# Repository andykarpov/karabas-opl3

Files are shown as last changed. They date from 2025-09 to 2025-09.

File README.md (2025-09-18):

## Karabas-OPL3

Simple OPL3 sound card for ZX Spectrum (NemoBus). 
Inspired by a BomgeMoon soundcard :)

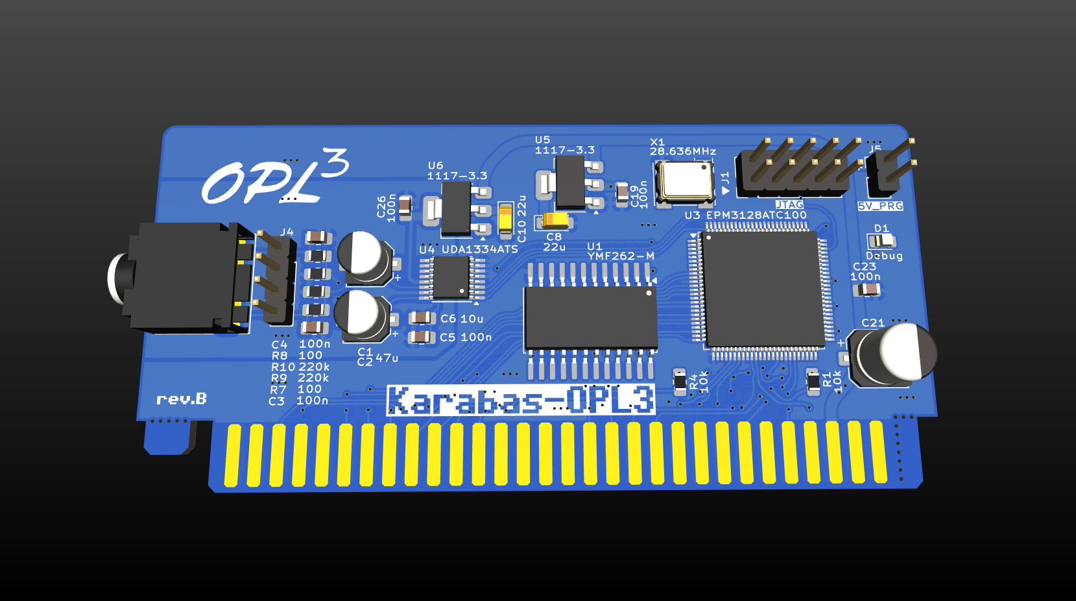
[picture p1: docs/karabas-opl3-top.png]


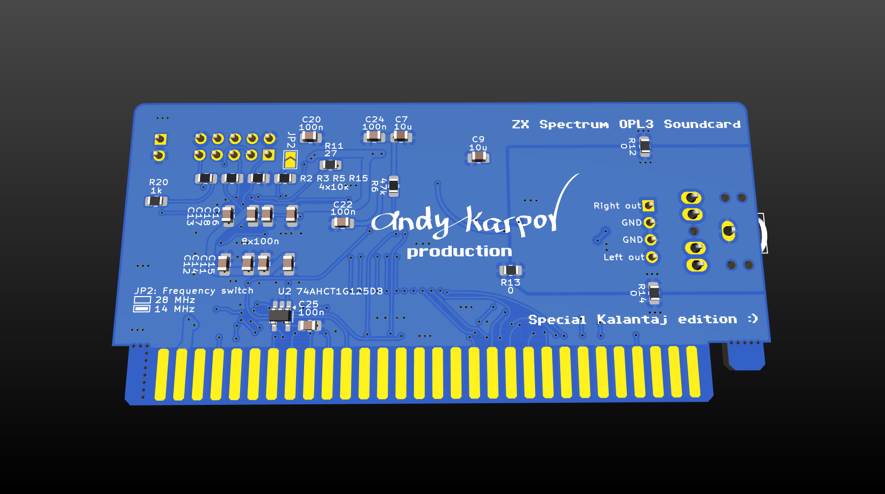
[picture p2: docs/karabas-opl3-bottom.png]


### Tech specs

* OPL3 sound by YMF-262-M
* 16-bit DAC UDA1334A
* EPM3128 CPLD
* Low profile PCB: 92x44mm (standard) and 131x44mm (xxl version)
* 5V only power required

### Changelog & current status

* Rev.A - initial release
* Rev.B - reduced pcb size, removed config switch

### Related projects

* BomgeMoon - [link](https://github.com/Kulicheg/BomgeMoon)
* ZX-Multisound - [link](https://github.com/UzixLS/zx-multisound)
* Turbo Sound FM - [link](http://www.nedopc.com/TURBOSOUND/ts-fm.php)
* ZXM-SoundCard - [link](http://micklab.ru/My%20Soundcard/ZXMSoundCard.htm)
* ZXM-GeneralSound - [link](http://micklab.ru/My%20Soundcard/ZXMGeneralSound.htm)
* NeoGS - [link](http://www.nedopc.com/gs/ngs.php)

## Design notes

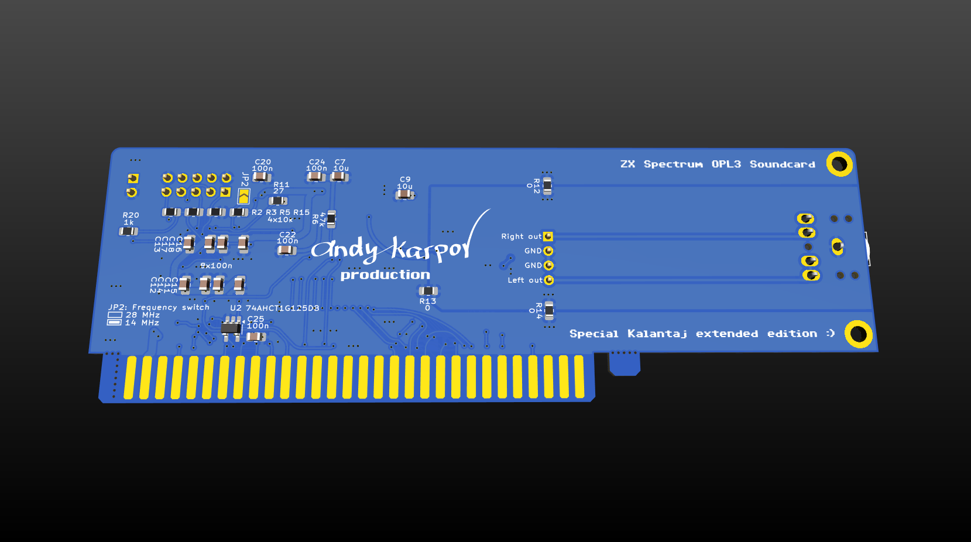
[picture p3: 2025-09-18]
docs/karabas-opl3-xxl-bottom.png

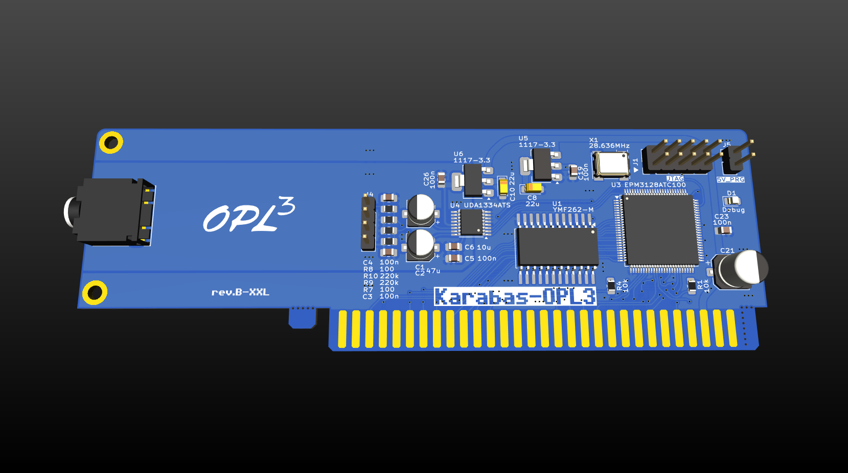
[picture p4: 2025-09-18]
docs/karabas-opl3-xxl-top.png

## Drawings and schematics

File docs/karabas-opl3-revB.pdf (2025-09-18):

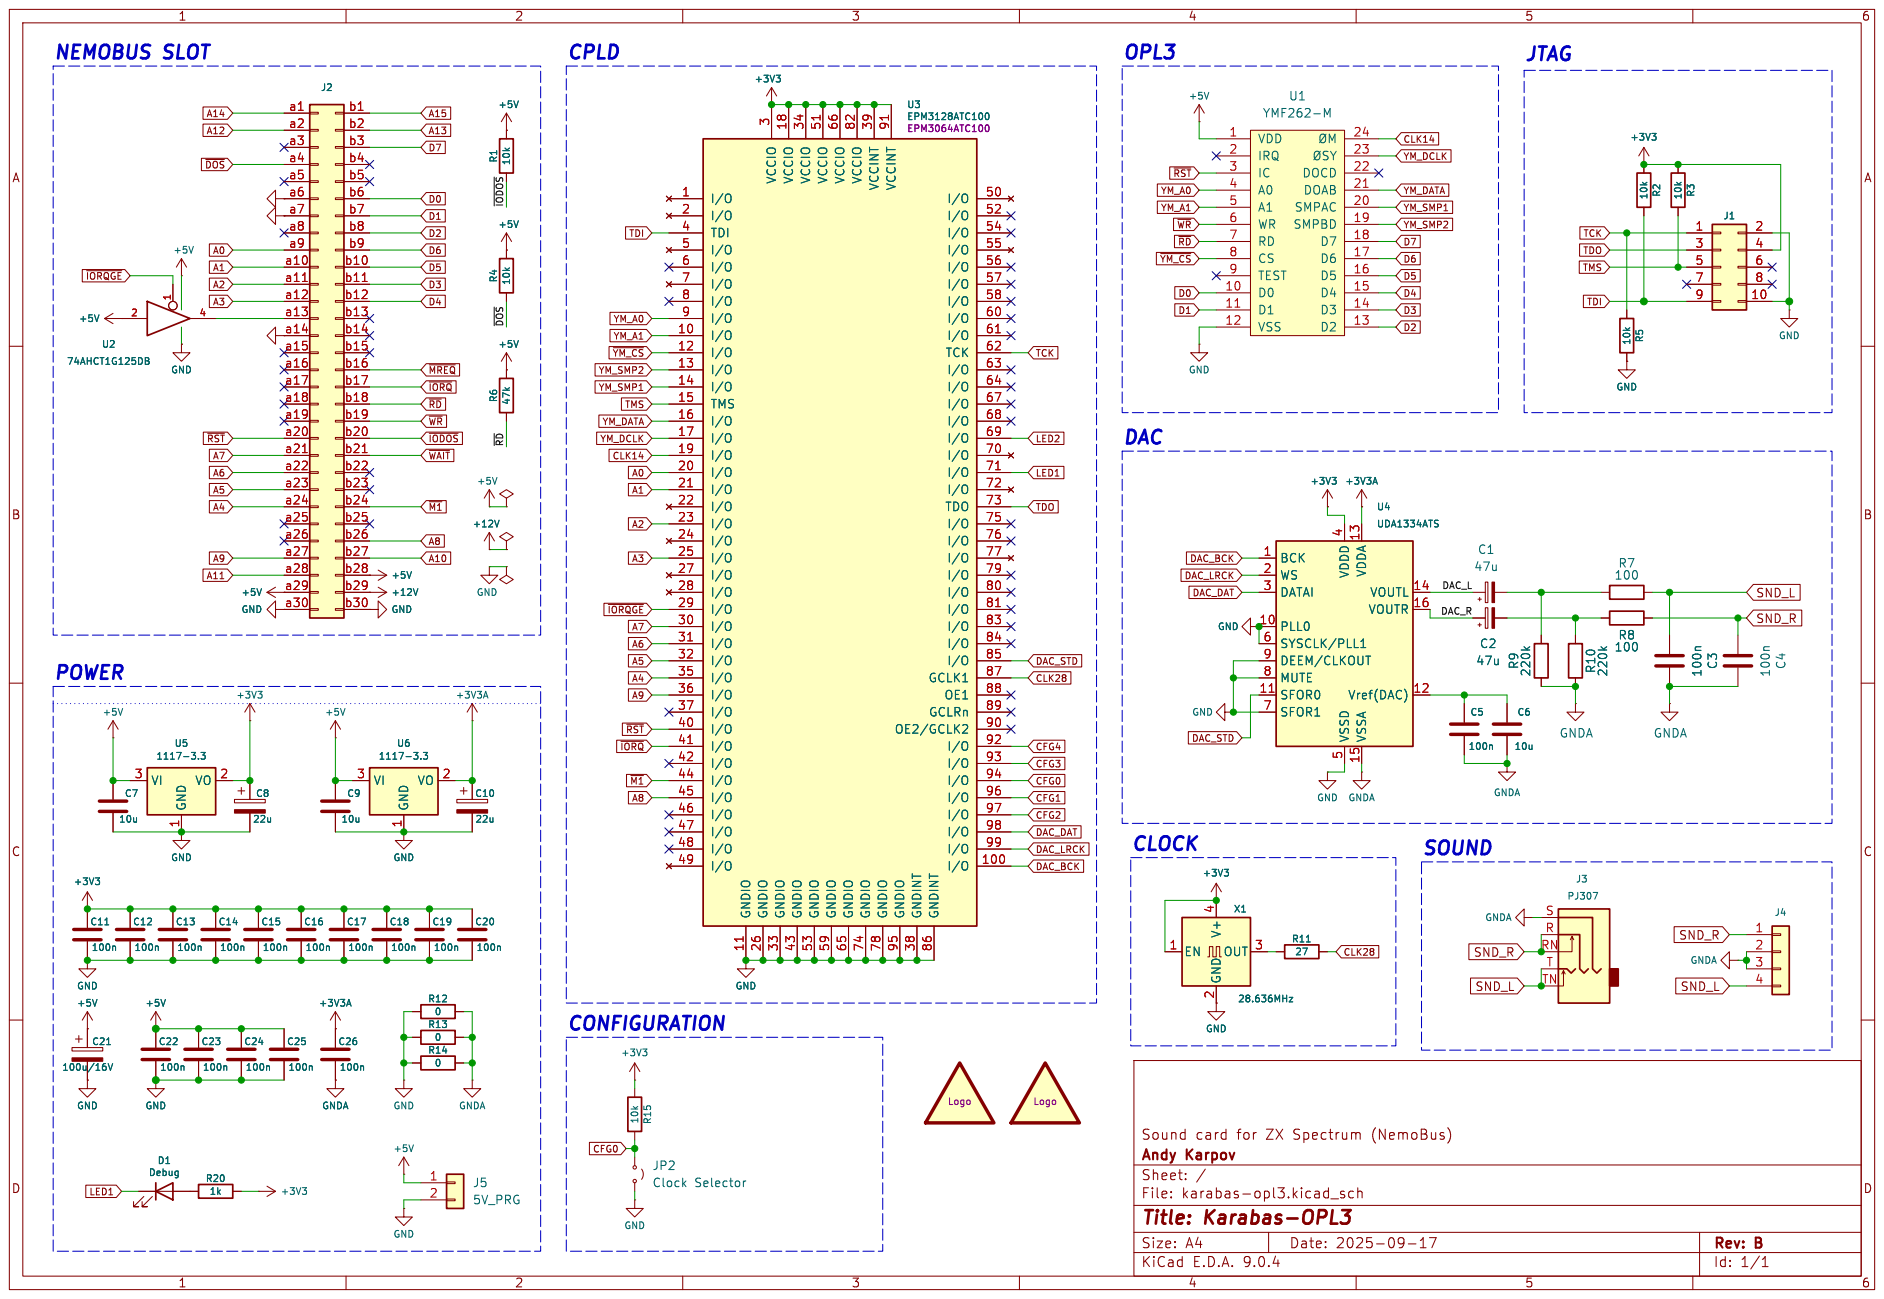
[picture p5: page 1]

3 GNDIO 33 VCCIO 18 GNDIO 43 VCCIO 34 GNDIO 53 VCCIO 51 GNDIO 59 VCCIO 66 GNDIO 65 VCCIO 82 GNDIO 74 VCCINT 39 GNDIO 78 VCCINT 91 GNDIO 95 GNDINT 38 GNDINT 86

5 VDDA 13 VSSA 15 VOUTL 14 VOUTR 16 Vref(DAC) 12 10k R5

5 VDDA 13 VSSA 15 VOUTL 14 VOUTR 16 Vref(DAC) 12 U4 UDA1334ATS GND

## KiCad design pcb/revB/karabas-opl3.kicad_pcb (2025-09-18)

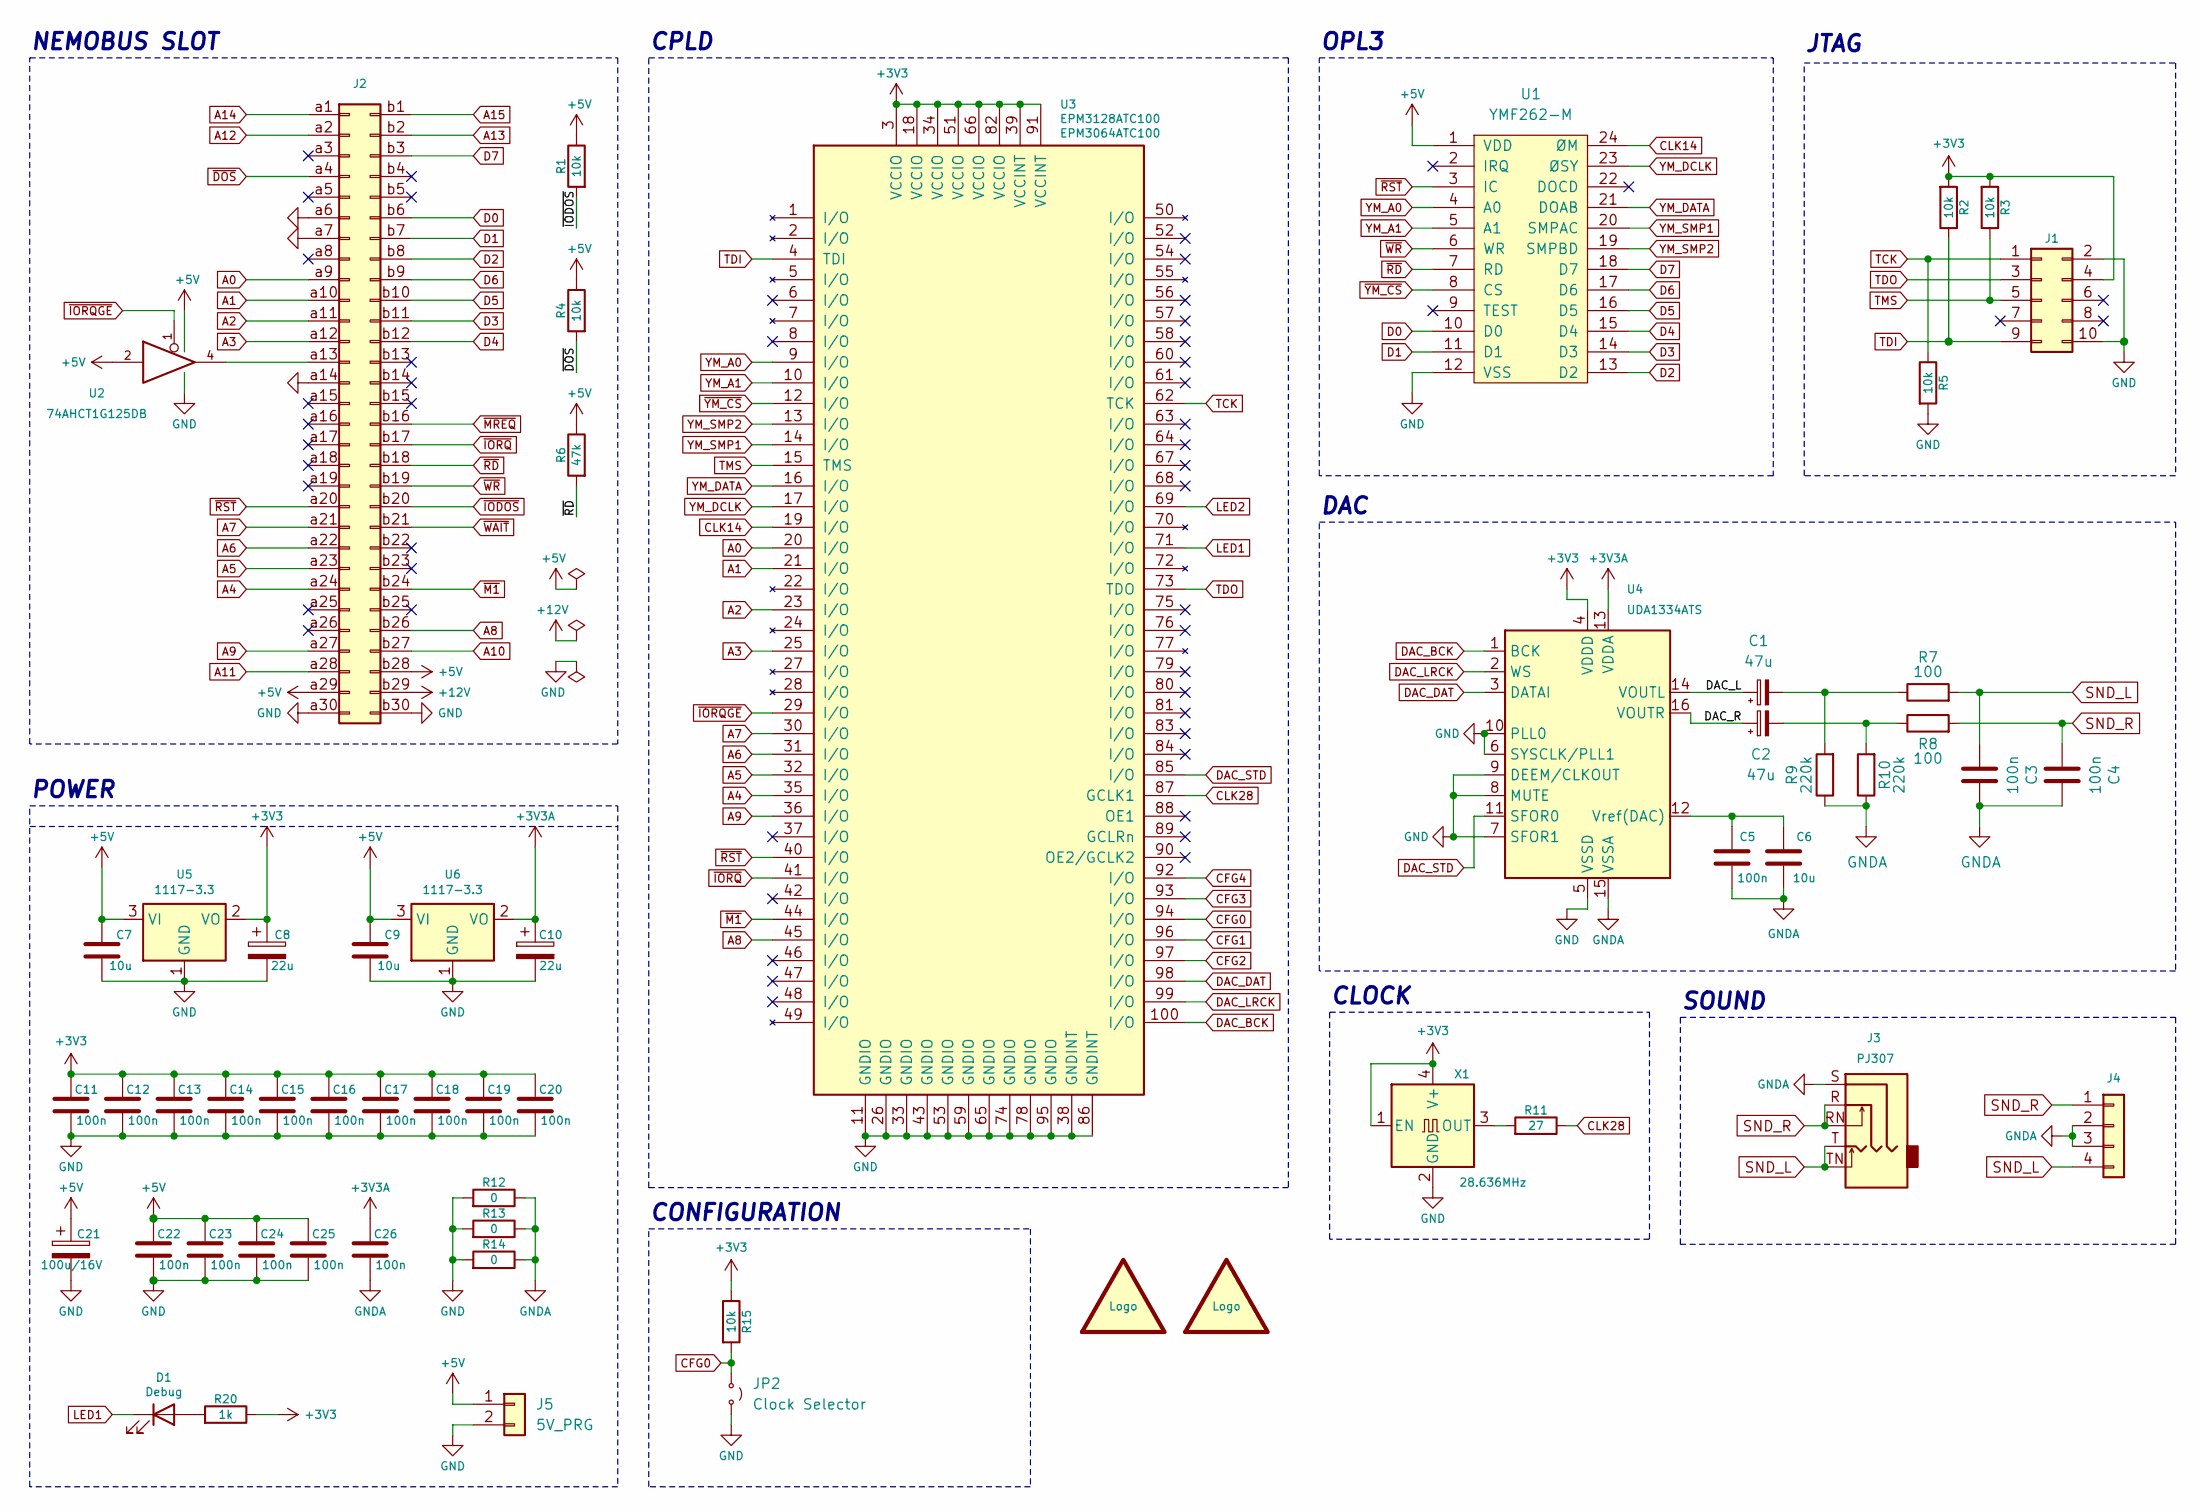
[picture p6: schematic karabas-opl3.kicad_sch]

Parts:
C1, C2: 47u; CP_Elec_5x5.9
C3, C4, C5, C11, C12, C13, C14, C15, C16, C17, C18, C19, C20, C22, C23, C24, C25, C26: 100n; C_0805_2012Metric_Pad1.18x1.45mm_HandSolder
C6, C7, C9: 10u; C_0805_2012Metric_Pad1.18x1.45mm_HandSolder
C8, C10: 22u; CP_EIA-3216-18_Kemet-A_HandSolder
C21: 100u/16V; CP_Elec_6.3x7.7
D1: Debug; LED_0805_2012Metric_Pad1.15x1.40mm_HandSolder
J1: Conn_02x05_Odd_Even; PinHeader_2x05_P2.54mm_Vertical
J2: Conn_02x30_Row_Letter_First; ZX_NEMO_60_EDGE
J3: PJ307; PJ-307
J4: Conn_01x04; PinHeader_1x04_P2.54mm_Vertical
J5: 5V_PRG; PinHeader_1x02_P2.54mm_Vertical
JP2: Clock Selector; SolderJumper-2_P1.3mm_Open_TrianglePad1.0x1.5mm
LOGO1: graphic; opl3
LOGO2: graphic; andy_karpov_logo4_silk
R1, R2, R3, R4, R5, R15: 10k; R_0805_2012Metric_Pad1.20x1.40mm_HandSolder
R6: 47k; R_0805_2012Metric_Pad1.20x1.40mm_HandSolder
R7, R8: 100; R_0805_2012Metric_Pad1.20x1.40mm_HandSolder
R9, R10: 220k; R_0805_2012Metric_Pad1.20x1.40mm_HandSolder
R11: 27; R_0805_2012Metric_Pad1.20x1.40mm_HandSolder
R12, R13, R14: 0; R_0805_2012Metric_Pad1.20x1.40mm_HandSolder
R20: 1k; R_0805_2012Metric_Pad1.20x1.40mm_HandSolder
U1: YMF262-M; ymf-262-m
U2: 74AHCT1G125DB; SOT-23-5_HandSoldering
U3: EPM3128ATC100; TQFP-100_14x14mm_P0.5mm
U4: UDA1334ATS; SSOP-16_4.4x5.2mm_P0.65mm-extended
U5, U6: 1117-3.3; SOT-223-3_TabPin2
X1: 28.636MHz; Oscillator_SMD_7050_7.0x5.0mm_mixed_3225

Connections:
+3V3: C8.1, C11.1, C12.1, C13.1, C14.1, C15.1, C16.1, C17.1, C18.1, C19.2, C20.2, J1.4, R2.2, R3.2, R15.1, R20.1, U3.3 (VCCIO), U3.18 (VCCIO), U3.34 (VCCIO), U3.39 (VCCINT), U3.51 (VCCIO), U3.66 (VCCIO), U3.82 (VCCIO), U3.91 (VCCINT), U4.4 (VDDD), U5.2 (VO), X1.1 (EN), X1.4 (V+)
+3V3A: C10.1, C26.1, U4.13 (VDDA), U6.2 (VO)
+5V: C7.1, C9.1, C21.1, C22.2, C23.2, C24.2, C25.2, J2.a29, J2.b28, J5.1, R1.1, R4.1, R6.1, U1.1 (VDD), U2.2, U2.5 (VCC), U5.3 (VI), U6.3 (VI)
+12V: J2.b29
/DAC_L: C1.1, U4.14 (VOUTL)
/DAC_R: C2.1, U4.16 (VOUTR)
A0: J2.a9, U3.20 (I/O)
A1: J2.a10, U3.21 (I/O)
A2: J2.a11, U3.23 (I/O)
A3: J2.a12, U3.25 (I/O)
A4: J2.a24, U3.35 (I/O)
A5: J2.a23, U3.32 (I/O)
A6: J2.a22, U3.31 (I/O)
A7: J2.a21, U3.30 (I/O)
A8: J2.b26, U3.45 (I/O)
A9: J2.a27, U3.36 (I/O)
A10: J2.b27
A11: J2.a28
A12: J2.a2
A13: J2.b2
A14: J2.a1
A15: J2.b1
CFG0: JP2.1 (A), R15.2, U3.94 (I/O)
CFG1: U3.96 (I/O)
CFG2: U3.97 (I/O)
CFG3: U3.93 (I/O)
CFG4: U3.92 (I/O)
CLK14: U1.24 (ØM), U3.19 (I/O)
CLK28: R11.1, U3.87 (GCLK1)
D0: J2.b6, U1.10 (D0)
D1: J2.b7, U1.11 (D1)
D2: J2.b8, U1.13 (D2)
D3: J2.b11, U1.14 (D3)
D4: J2.b12, U1.15 (D4)
D5: J2.b10, U1.16 (D5)
D6: J2.b9, U1.17 (D6)
D7: J2.b3, U1.18 (D7)
DAC_BCK: U3.100 (I/O), U4.1 (BCK)
DAC_DAT: U3.98 (I/O), U4.3 (DATAI)
DAC_LRCK: U3.99 (I/O), U4.2 (WS)
DAC_STD: U3.85 (I/O), U4.11 (SFOR0)
GND: C7.2, C8.2, C9.2, C10.2, C11.2, C12.2, C13.2, C14.2, C15.2, C16.2, C17.2, C18.2, C19.1, C20.1, C21.2, C22.1, C23.1, C24.1, C25.1, J1.2, J1.10, J2.a6, J2.a7, J2.a14, J2.a30, J2.b30, J5.2, JP2.2 (B), R5.2, R12.2, R13.2, R14.2, U1.12 (VSS), U2.3 (GND), U3.11 (GNDIO), U3.26 (GNDIO), U3.33 (GNDIO), U3.38 (GNDINT), U3.43 (GNDIO), U3.53 (GNDIO), U3.59 (GNDIO), U3.65 (GNDIO), U3.74 (GNDIO), U3.78 (GNDIO), U3.86 (GNDINT), U3.95 (GNDIO), U4.5 (VSSD), U4.6 (SYSCLK/PLL1), U4.7 (SFOR1), U4.8 (MUTE), U4.9 (DEEM/CLKOUT), U4.10 (PLL0), U5.1 (GND), U6.1 (GND), X1.2 (GND)
GNDA: C3.2, C4.2, C5.1, C6.1, C26.2, J3.S, J4.2, J4.3, R9.1, R10.1, R12.1, R13.1, R14.1, U4.15 (VSSA)
LED1: D1.1 (K), U3.71 (I/O)
LED2: U3.69 (I/O)
unnamed: C1.2, R7.1, R9.2
unnamed: C2.2, R8.1, R10.2
unnamed: D1.2 (A), R20.2
unnamed: J2.a13, U2.4
unnamed: C5.2, C6.2, U4.12 (Vref(DAC))
unnamed: R11.2, X1.3 (OUT)
SND_L: C3.1, J3.T, J3.TN, J4.4, R7.2
SND_R: C4.1, J3.R, J3.RN, J4.1, R8.2
TCK: J1.1, R5.1, U3.62 (TCK)
TDI: J1.9, R2.1, U3.4 (TDI)
TDO: J1.3, U3.73 (TDO)
TMS: J1.5, R3.1, U3.15 (TMS)
YM_A0: U1.4 (A0), U3.9 (I/O)
YM_A1: U1.5 (A1), U3.10 (I/O)
YM_DATA: U1.21 (DOAB), U3.16 (I/O)
YM_DCLK: U1.23 (ØSY), U3.17 (I/O)
YM_SMP1: U1.20 (SMPAC), U3.14 (I/O)
YM_SMP2: U1.19 (SMPBD), U3.13 (I/O)
~DOS: J2.a4, R4.2
~IODOS: J2.b20, R1.2
~IORQGE: U2.1, U3.29 (I/O)
~IORQ: J2.b17, U3.41 (I/O)
~M1: J2.b24, U3.44 (I/O)
~MREQ: J2.b16
~RD: J2.b18, R6.2, U1.7 (RD)
~RST: J2.a20, U1.3 (IC), U3.40 (I/O)
~WAIT: J2.b21
~WR: J2.b19, U1.6 (WR)
~YM_CS: U1.8 (CS), U3.12 (I/O)

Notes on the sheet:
SOUND
CPLD
DAC
CONFIGURATION
OPL3
JTAG
POWER
CLOCK
NEMOBUS SLOT

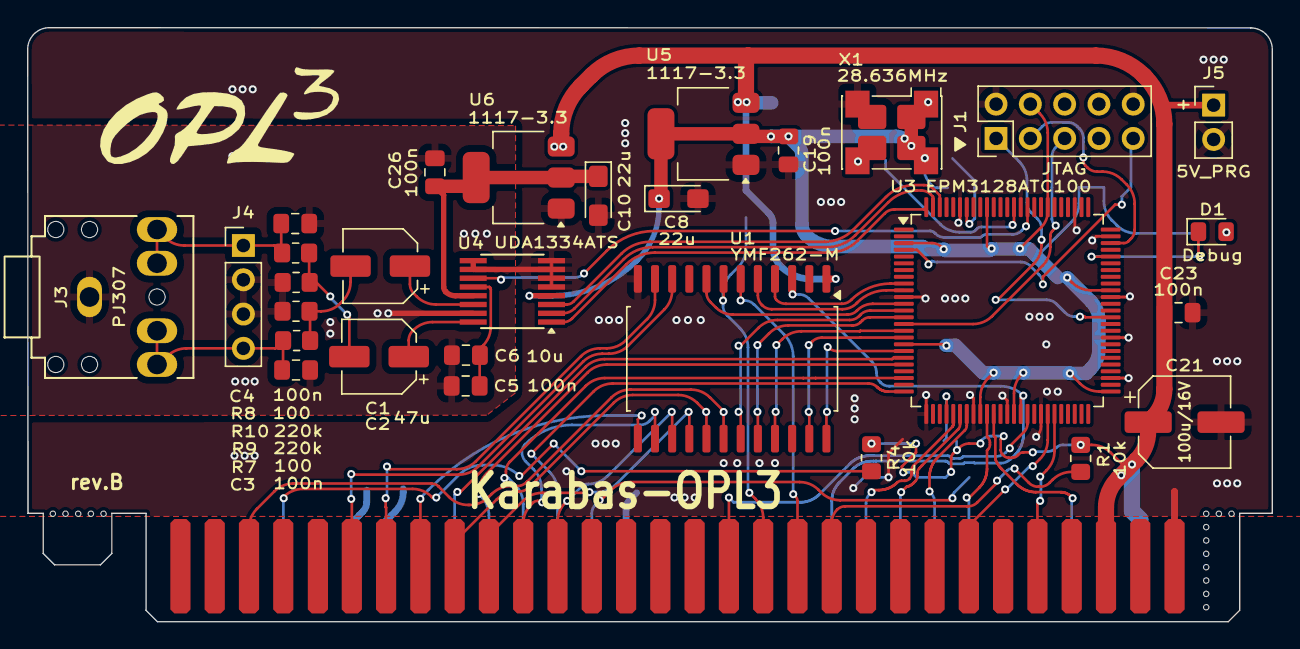
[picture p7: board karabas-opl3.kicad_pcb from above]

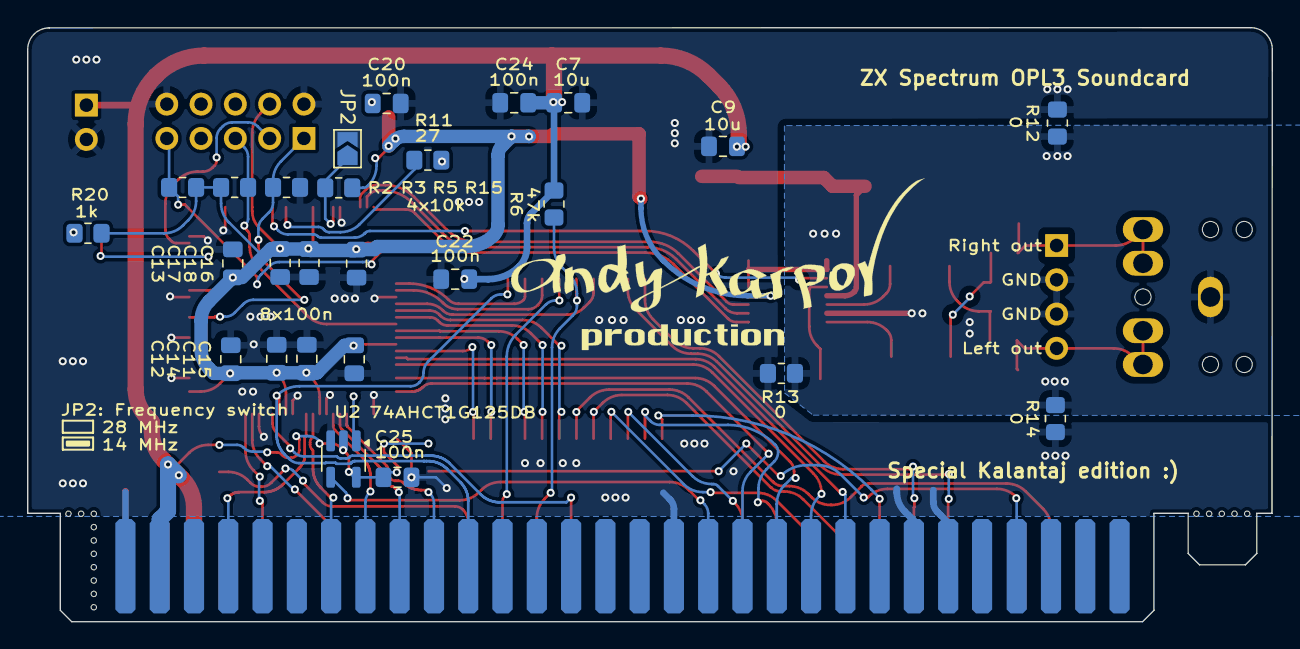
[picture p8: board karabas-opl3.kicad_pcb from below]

Board: 2 copper layers, 92.2 x 44.0 mm, 58 parts (27 on the bottom side), 60 nets.

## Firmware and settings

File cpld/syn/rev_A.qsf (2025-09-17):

# -------------------------------------------------------------------------- #
#
# Copyright (C) 1991-2013 Altera Corporation
# Your use of Altera Corporation's design tools, logic functions 
# and other software and tools, and its AMPP partner logic 
# functions, and any output files from any of the foregoing 
# (including device programming or simulation files), and any 
# associated documentation or information are expressly subject 
# to the terms and conditions of the Altera Program License 
# Subscription Agreement, Altera MegaCore Function License 
# Agreement, or other applicable license agreement, including, 
# without limitation, that your use is for the sole purpose of 
# programming logic devices manufactured by Altera and sold by 
# Altera or its authorized distributors.  Please refer to the 
# applicable agreement for further details.
#
# -------------------------------------------------------------------------- #
#
# Quartus II 64-Bit
# Version 13.0.1 Build 232 06/12/2013 Service Pack 1 SJ Full Version
# Date created = 12:04:27  October 04, 2020
#
# -------------------------------------------------------------------------- #
#
# Notes:
#
# 1) The default values for assignments are stored in the file:
#		zx_multisound_assignment_defaults.qdf
#    If this file doesn't exist, see file:
#		assignment_defaults.qdf
#
# 2) Altera recommends that you do not modify this file. This
#    file is updated automatically by the Quartus II software
#    and any changes you make may be lost or overwritten.
#
# -------------------------------------------------------------------------- #


set_global_assignment -name FAMILY MAX3000A
set_global_assignment -name DEVICE "EPM3128ATC100-10"
set_global_assignment -name TOP_LEVEL_ENTITY karabas_opl3
set_global_assignment -name ORIGINAL_QUARTUS_VERSION "13.0 SP1"
set_global_assignment -name PROJECT_CREATION_TIME_DATE "12:04:27  OCTOBER 04, 2020"
set_global_assignment -name LAST_QUARTUS_VERSION "13.0 SP1"
set_global_assignment -name PROJECT_OUTPUT_DIRECTORY output
set_global_assignment -name DEVICE_FILTER_PIN_COUNT 144
set_global_assignment -name ERROR_CHECK_FREQUENCY_DIVISOR "-1"
set_global_assignment -name SDC_FILE clocks.sdc
set_global_assignment -name VERILOG_FILE ../rtl/top.v
set_global_assignment -name VHDL_INPUT_VERSION VHDL_2008
set_global_assignment -name VHDL_SHOW_LMF_MAPPING_MESSAGES OFF
set_global_assignment -name VERILOG_INPUT_VERSION VERILOG_2001
set_global_assignment -name VERILOG_SHOW_LMF_MAPPING_MESSAGES OFF
set_global_assignment -name MAX7000_DEVICE_IO_STANDARD "3.3-V LVTTL"
set_global_assignment -name SAVE_DISK_SPACE OFF
set_global_assignment -name TIMEQUEST_MULTICORNER_ANALYSIS OFF
set_global_assignment -name SYNTH_TIMING_DRIVEN_SYNTHESIS OFF

set_location_assignment PIN_9 -to ym_a[0]
set_location_assignment PIN_10 -to ym_a[1]
set_location_assignment PIN_12 -to n_ym_cs
set_location_assignment PIN_13 -to ym_smp[1]
set_location_assignment PIN_16 -to ym_data
set_location_assignment PIN_17 -to ym_dclk
set_location_assignment PIN_19 -to clk14
set_location_assignment PIN_20 -to a[0]
set_location_assignment PIN_21 -to a[1]
set_location_assignment PIN_23 -to a[2]
set_location_assignment PIN_29 -to n_iorqge
set_location_assignment PIN_30 -to a[7]
set_location_assignment PIN_31 -to a[6]
set_location_assignment PIN_32 -to a[5]
set_location_assignment PIN_35 -to a[4]
set_location_assignment PIN_36 -to a[9]
set_location_assignment PIN_41 -to n_iorq
set_location_assignment PIN_44 -to n_m1
set_location_assignment PIN_45 -to a[8]
set_location_assignment PIN_87 -to clk28
set_location_assignment PIN_92 -to cfg[4]
set_location_assignment PIN_93 -to cfg[3]
set_location_assignment PIN_94 -to cfg[0]
set_location_assignment PIN_96 -to cfg[1]
set_location_assignment PIN_97 -to cfg[2]
set_location_assignment PIN_98 -to dac_dat
set_location_assignment PIN_99 -to dac_lrck
set_location_assignment PIN_100 -to dac_bck

set_global_assignment -name MAX7000_OPTIMIZATION_TECHNIQUE BALANCED
set_global_assignment -name PRE_MAPPING_RESYNTHESIS OFF
set_global_assignment -name OPTIMIZE_HOLD_TIMING OFF
set_global_assignment -name OPTIMIZE_MULTI_CORNER_TIMING ON
set_global_assignment -name FITTER_EFFORT "STANDARD FIT"
set_global_assignment -name RESERVE_ALL_UNUSED_PINS_NO_OUTPUT_GND "AS INPUT TRI-STATED"

set_location_assignment PIN_14 -to ym_smp[0]
set_location_assignment PIN_85 -to dac_std
set_location_assignment PIN_71 -to led[0]
set_location_assignment PIN_69 -to led[1]
set_location_assignment PIN_25 -to a[3]
set_location_assignment PIN_40 -to n_rst
set_instance_assignment -name GLOBAL_SIGNAL "GLOBAL CLOCK" -to clk28

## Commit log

2025-07-25 initial commit, revA
    [karabas-opl3.kicad_pcb, karabas-opl3.kicad_sch]
2025-07-25 Updated references
    [karabas-opl3.kicad_pcb]
2025-07-26 Added debug leds
    [karabas-opl3.kicad_pcb, karabas-opl3.kicad_sch]
2025-07-26 Latest changes
    [karabas-opl3.kicad_pcb]
2025-07-27 Added pj307 3d model
    [karabas-opl3.kicad_pcb]
2025-08-06 Added universal footprint for 3225+5070 osc
    [karabas-opl3.kicad_pcb, karabas-opl3.kicad_sch]
2025-08-06 Updated 5V lane - removed loop
    [karabas-opl3.kicad_pcb, karabas-opl3.kicad_sch]
2025-09-17 Small footprint fixes
    [karabas-opl3.kicad_pcb, karabas-opl3.kicad_sch]
2025-09-18 Updated revB gerbers
    [karabas-opl3.kicad_pcb]
2025-09-18 removed cfg switches, keep only one to select oscillator frequency
2025-09-18 Fixed measures for rev.B
    [karabas-opl3.kicad_pcb]
